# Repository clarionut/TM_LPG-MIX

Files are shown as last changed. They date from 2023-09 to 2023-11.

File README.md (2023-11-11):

# TM_LPG-MIX

This repository provides a KiCad schematic and PCB layout for a variant of the TM-LPG-X expander (https://github.com/morganmcw/TM-LPG-X) and the orignal Turing Machine Vactrol Mix expander (https://github.com/TomWhitwell/TuringMixExpander).

It includes the variation switches of the TM-LPG-X, but can be built using capacitors (LPG), resistors (Mix) or with a pin header to allow switching between LPG or Mix mode via a front panel switch (with the resistors and capacitors mounted on the switch).

In their original forms an LPG module would be connected to the Turing Machine PULSES header and a Mix module to the GATES header. This design includes a daughter board which allows both headers to be connected simultaneously. The active connection is selected by a switch or a gate voltage input (the gate input is only active when the switch is OFF).

Taken together, these features allow the unit to be built as a TM-LPG-X, a Turing Machine Vactrol Mix with variation switches, or as a fully configurable combination of the two. Experience since first completing this project has shown that the combination of home made vactrols (https://www.thingiverse.com/thing:6178403) using ultrabright red LEDs and GL5528 LDRs with 220nF capacitors for C5 and C6 leads to such a rapid decay time that the low-pass gate effect is essentially inaudible, though it is visible on an oscilloscope. Reducing the value of these capacitors to 10nF gives a decay time in the region of 0.5 - 1 second which is much more suitable for an LPG. In a similar way, the decay time in Mix mode can be increased by using resistors with a value greater than 10k in place of the capacitors. E.g. 47k resistors in Mix mode give a similar decay time to the 10nF capacitors in LPG mode. A very interesting further extension is to use a dual resistor (5k) / potentiometer (50k) combination in place of the fixed 'Mix' resistors, and a 2-pole 3- or 4-way switch to select the LPG capacitor values (e.g. 100, 33, 10 & 4.7nF) in order to make the decay time adjustable in both modes. I've now tested this ehancement and it is very much worthwhile. I used the resistor and capacitor values shown, but different values may work better depending on the characteristics of the vactrols used.

The PCB layout file uses a custom footprint for the vactrols and a custom model for the 3D viewer. There are included in the TM_LPG-MIX folder - you will have to move them to appropriate locations and tell KiCad where to find them. The PCB design is intended to be processed using the kicad-round-tracks add-on (https://github.com/mitxela/kicad-round-tracks). The schematic also includes a custom audio jack symbol, so I've included both the cache-lib file for the project and a copy of my customised symbols lbrary.

This design is Creative Commons Licensed by Chris Earnshaw: CC-BY-SA - inherited from the parent designs.

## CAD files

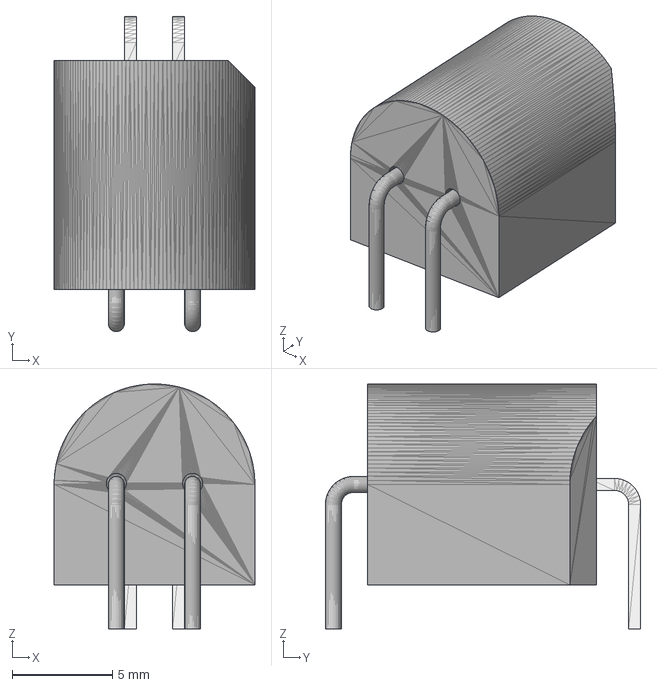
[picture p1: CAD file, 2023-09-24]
TM_LPG-MIX/vactrolModel.step
10.0 x 15.7 x 12.2 mm

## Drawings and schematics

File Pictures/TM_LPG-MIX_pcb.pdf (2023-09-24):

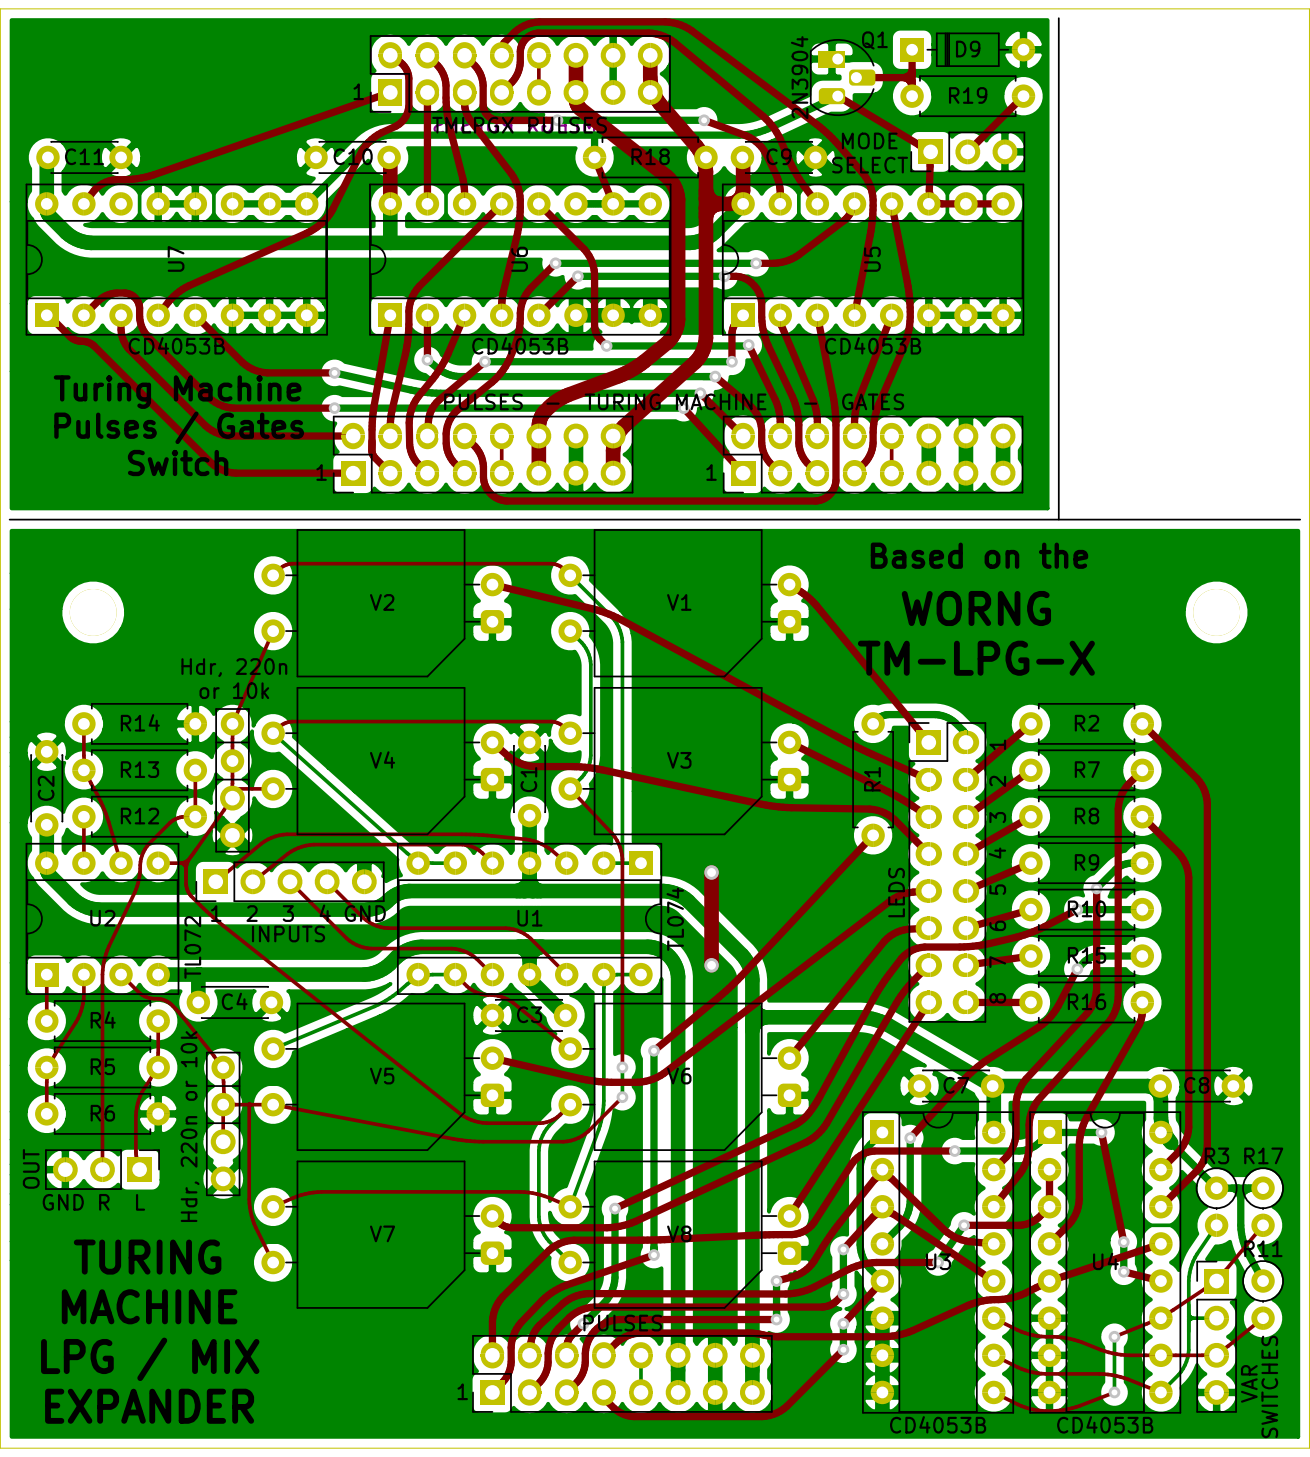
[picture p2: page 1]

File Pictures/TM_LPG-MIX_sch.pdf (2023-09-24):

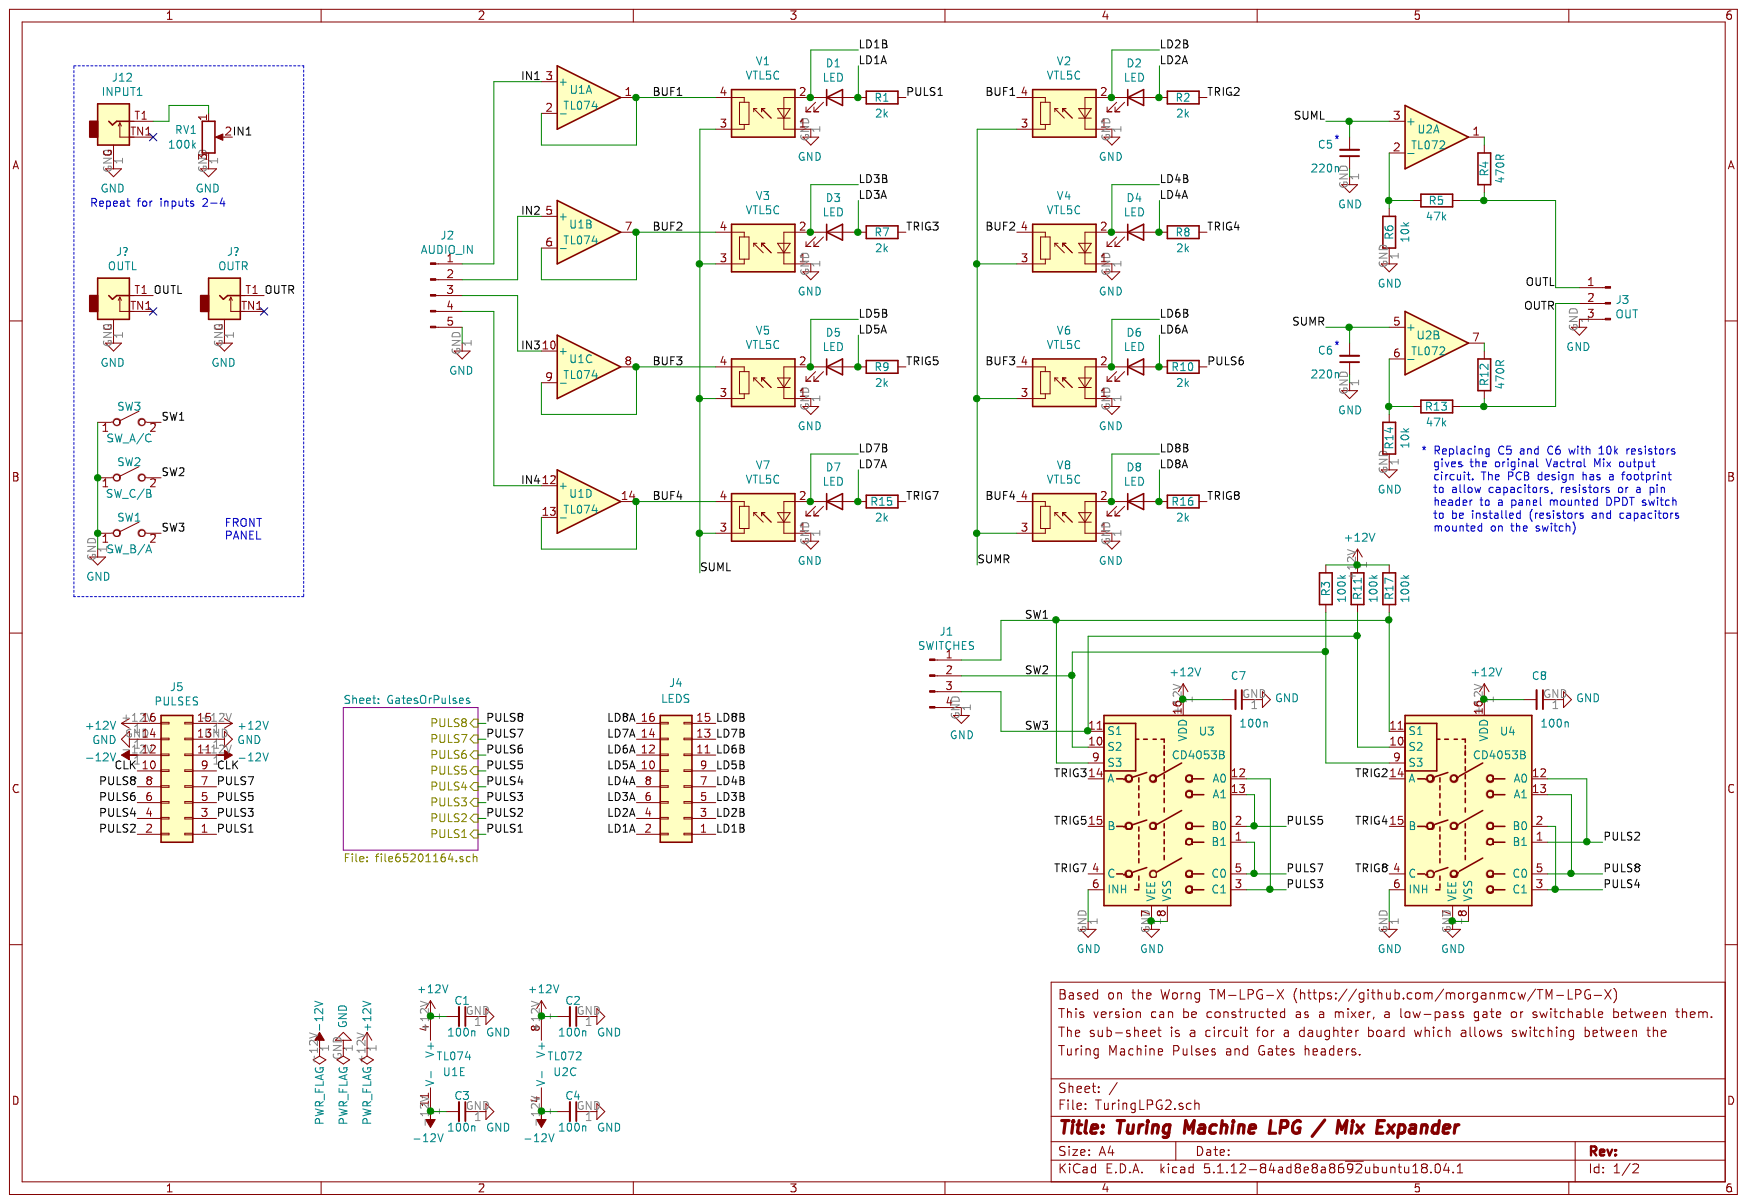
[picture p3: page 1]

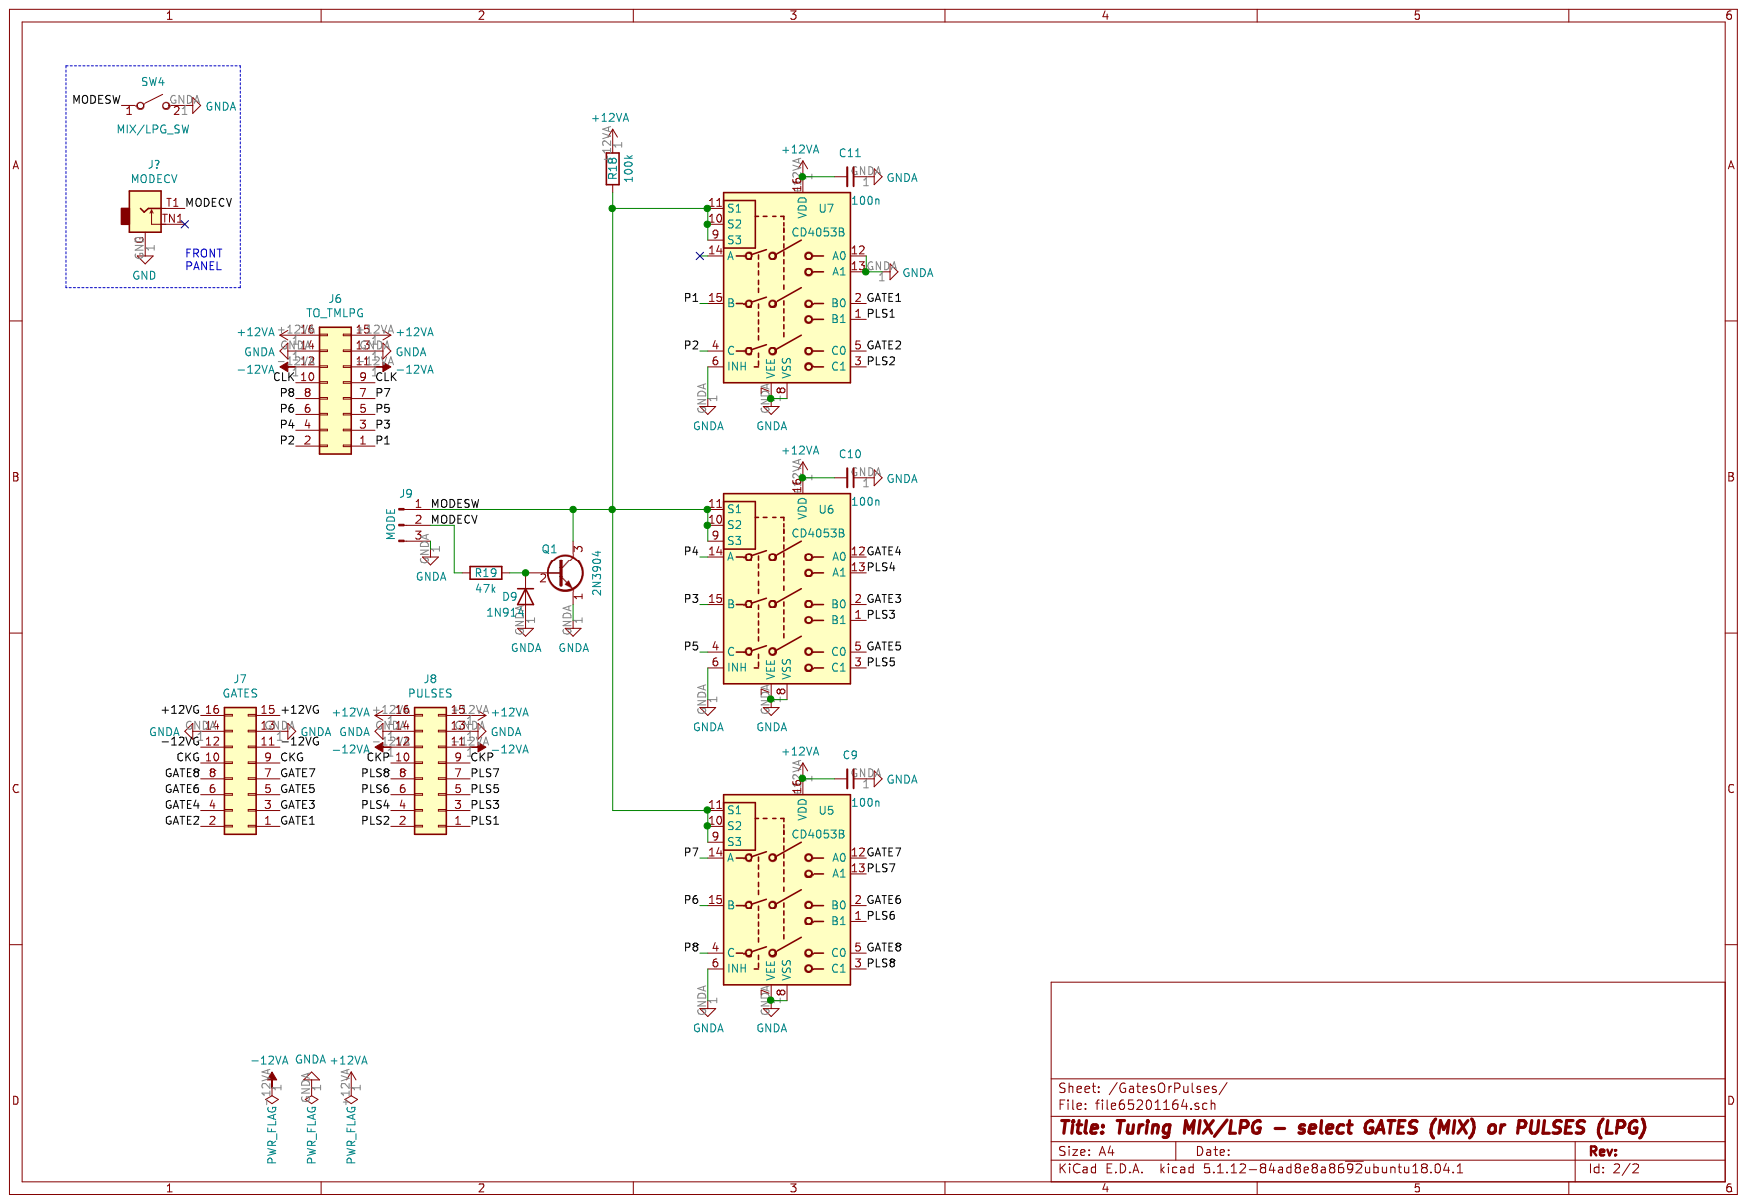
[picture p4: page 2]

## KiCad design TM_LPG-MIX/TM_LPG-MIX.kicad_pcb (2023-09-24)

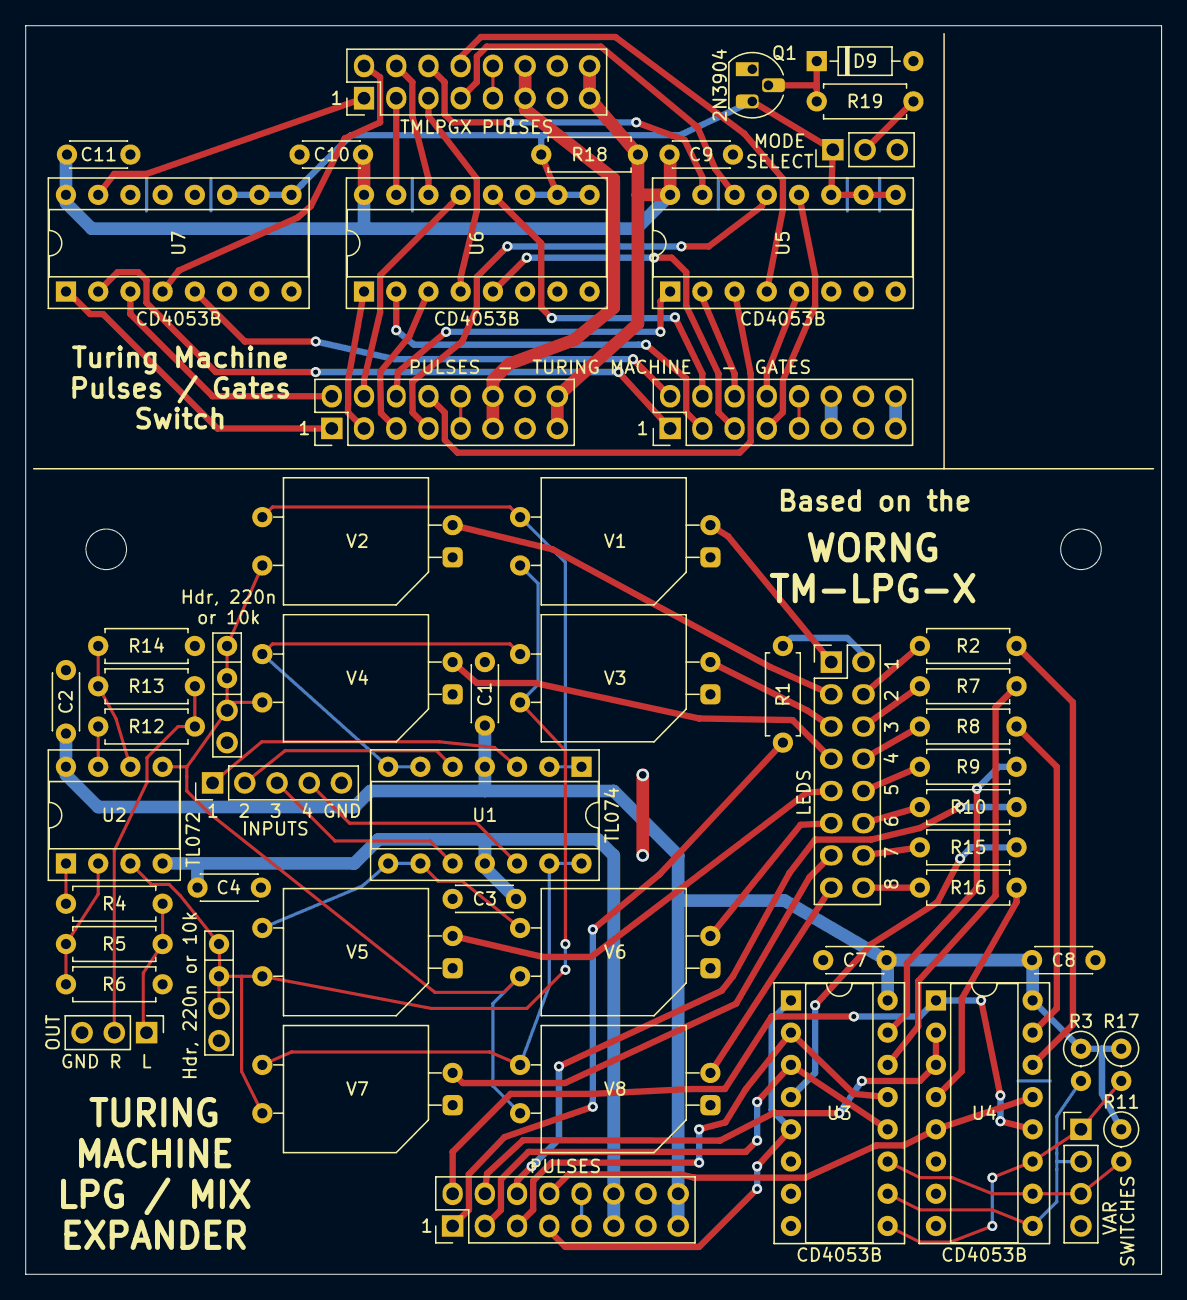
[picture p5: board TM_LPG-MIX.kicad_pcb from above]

Board: 2 copper layers, 89.5 x 98.4 mm, 56 parts (1 on the bottom side), 88 nets.

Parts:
C1, C2, C3, C4, C7, C8, C9, C10, C11: 100n; C_Disc_D4.3mm_W1.9mm_P5.00mm
C5, C6: 220n; C_Rect_L7.0mm_W2.0mm_P5.00mm
D9: 1N914; D_DO-35_SOD27_P7.62mm_Horizontal
J1: SWITCHES; PinHeader_1x04_P2.54mm_Vertical
J2: AUDIO_IN; PinHeader_1x05_P2.54mm_Vertical
J3: OUT; PinHeader_1x03_P2.54mm_Vertical
J4: LEDS; PinHeader_2x08_P2.54mm_Vertical
J5, J8: PULSES; PinHeader_2x08_P2.54mm_Vertical
J6: TO_TMLPG; PinSocket_2x08_P2.54mm_Vertical
J7: GATES; PinHeader_2x08_P2.54mm_Vertical
J9: MODE; PinHeader_1x03_P2.54mm_Vertical
Q1: 2N3904; TO-92_HandSolder
R1, R2, R7, R8, R9, R10, R15, R16: 2k; R_Axial_DIN0207_L6.3mm_D2.5mm_P7.62mm_Horizontal
R3, R11, R17: 100k; R_Axial_DIN0207_L6.3mm_D2.5mm_P2.54mm_Vertical
R4, R12: 470R; R_Axial_DIN0207_L6.3mm_D2.5mm_P7.62mm_Horizontal
R5, R13, R19: 47k; R_Axial_DIN0207_L6.3mm_D2.5mm_P7.62mm_Horizontal
R6, R14: 10k; R_Axial_DIN0207_L6.3mm_D2.5mm_P7.62mm_Horizontal
R18: 100k; R_Axial_DIN0207_L6.3mm_D2.5mm_P7.62mm_Horizontal
U1: TL074; DIP-14_W7.62mm_Socket
U2: TL072; DIP-8_W7.62mm_Socket
U3, U4, U5, U6, U7: CD4053B; DIP-16_W7.62mm_Socket
V1, V2, V3, V4, V5, V6, V7, V8: VTL5C; CGE_vactrol

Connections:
+12V: C1.2, C2.2, C7.2, C8.2, J5.15, J5.16, R3.1, R11.1, R17.1, U1.4, U2.8, U3.16, U4.16
+12VA: C9.2, C10.2, C11.2, J6.15, J6.16, J8.15, J8.16, R18.1, U5.16, U6.16, U7.16
-12V: C3.2, C4.2, J5.11, J5.12, U1.11, U2.4
-12VA: J6.11, J6.12, J8.11, J8.12
/BUF1: U1.1, U1.2, V1.4, V2.4
/BUF2: U1.6, U1.7, V3.4, V4.4
/BUF3: U1.8, U1.9, V5.4, V6.4
/BUF4: U1.13, U1.14, V7.4, V8.4
/CLK: J5.9, J5.10
/GatesOrPulses/+12VG: J7.15, J7.16
/GatesOrPulses/-12VG: J7.11, J7.12
/GatesOrPulses/CKG: J7.9, J7.10
/GatesOrPulses/CKP: J8.9, J8.10
/GatesOrPulses/CLK: J6.9, J6.10
/GatesOrPulses/GATE1: J7.1, U7.2
/GatesOrPulses/GATE2: J7.2, U7.5
/GatesOrPulses/GATE3: J7.3, U6.2
/GatesOrPulses/GATE4: J7.4, U6.12
/GatesOrPulses/GATE5: J7.5, U6.5
/GatesOrPulses/GATE6: J7.6, U5.2
/GatesOrPulses/GATE7: J7.7, U5.12
/GatesOrPulses/GATE8: J7.8, U5.5
/GatesOrPulses/MODECV: J9.2, R19.2
/GatesOrPulses/MODESW: J9.1, Q1.3, R18.2, U5.9, U5.10, U5.11, U6.9, U6.10, U6.11, U7.9, U7.10, U7.11
/GatesOrPulses/P1: J6.1, U7.15
/GatesOrPulses/P2: J6.2, U7.4
/GatesOrPulses/P3: J6.3, U6.15
/GatesOrPulses/P4: J6.4, U6.14
/GatesOrPulses/P5: J6.5, U6.4
/GatesOrPulses/P6: J6.6, U5.15
/GatesOrPulses/P7: J6.7, U5.14
/GatesOrPulses/P8: J6.8, U5.4
/GatesOrPulses/PLS1: J8.1, U7.1
/GatesOrPulses/PLS2: J8.2, U7.3
/GatesOrPulses/PLS3: J8.3, U6.1
/GatesOrPulses/PLS4: J8.4, U6.13
/GatesOrPulses/PLS5: J8.5, U6.3
/GatesOrPulses/PLS6: J8.6, U5.1
/GatesOrPulses/PLS7: J8.7, U5.13
/GatesOrPulses/PLS8: J8.8, U5.3
/IN1: J2.1, U1.3
/IN2: J2.2, U1.5
/IN3: J2.3, U1.10
/IN4: J2.4, U1.12
/LD1A: J4.2, R1.1
/LD1B: J4.1, V1.2
/LD2A: J4.4, R2.1
/LD2B: J4.3, V2.2
/LD3A: J4.6, R7.1
/LD3B: J4.5, V3.2
/LD4A: J4.8, R8.1
/LD4B: J4.7, V4.2
/LD5A: J4.10, R9.1
/LD5B: J4.9, V5.2
/LD6A: J4.12, R10.1
/LD6B: J4.11, V6.2
/LD7A: J4.14, R15.1
/LD7B: J4.13, V7.2
/LD8A: J4.16, R16.1
/LD8B: J4.15, V8.2
/OUTL: J3.1, R4.2, R5.1
/OUTR: J3.2, R12.2, R13.1
/PULS1: J5.1, R1.2
/PULS2: J5.2, U4.1, U4.12
/PULS3: J5.3, U3.3, U3.12
/PULS4: J5.4, U4.2, U4.3
/PULS5: J5.5, U3.2, U3.13
/PULS6: J5.6, R10.2
/PULS7: J5.7, U3.1, U3.5
/PULS8: J5.8, U4.5, U4.13
/SUML: C5.2, U2.3, V1.3, V3.3, V5.3, V7.3
/SUMR: C6.2, U2.5, V2.3, V4.3, V6.3, V8.3
/SW1: J1.1, R17.2, U3.9, U4.11
/SW2: J1.2, R3.2, U3.10, U4.9
/SW3: J1.3, R11.2, U3.11, U4.10
/TRIG2: R2.2, U4.14
/TRIG3: R7.2, U3.14
/TRIG4: R8.2, U4.15
/TRIG5: R9.2, U3.15
/TRIG7: R15.2, U3.4
/TRIG8: R16.2, U4.4
GND: C1.1, C2.1, C3.1, C4.1, C5.1, C6.1, C7.1, C8.1, J1.4, J2.5, J3.3, J5.13, J5.14, R6.2, R14.2, U3.6, U3.7, U3.8, U4.6, U4.7, U4.8, V1.1, V2.1, V3.1, V4.1, V5.1, V6.1, V7.1, V8.1
GNDA: C9.1, C10.1, C11.1, D9.2, J6.13, J6.14, J7.13, J7.14, J8.13, J8.14, J9.3, Q1.1, U5.6, U5.7, U5.8, U6.6, U6.7, U6.8, U7.6, U7.7, U7.8, U7.12, U7.13
unnamed: D9.1, Q1.2, R19.1
unnamed: R4.1, U2.1
unnamed: R5.2, R6.1, U2.2
unnamed: R12.1, U2.7
unnamed: R13.2, R14.1, U2.6

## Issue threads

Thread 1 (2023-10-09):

Missing symbols

holmesrichards, 2023-10-09:
The file `TM_LPG-MIX_cache.lib` is missing causing some symbols to be missing in the schematic editor

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

clarionut, 2023-10-09:
Sorry about that! I've uploaded the cache-lib file. I'm a bit puzzled about the items that are missing - on the main schematic they're male connectors and one of the items missing in the front panel box is simply a potentiometer. The other panel items are customised audio jack symbols. I've added a copy of my custom symbols library too. Hope this fixes the issue.

holmesrichards, 2023-10-09:
I think the jacks were from your custom  symbols. As for the pot and the headers, I'm using KiCad 7 and those now have different names (R_Pot became R_Potentiometer and Conn_nnxmm_Male became Conn_nnxmm_Pin) so it doesn't know what those are without the symbols cache.

Closed 2023-10-09.
